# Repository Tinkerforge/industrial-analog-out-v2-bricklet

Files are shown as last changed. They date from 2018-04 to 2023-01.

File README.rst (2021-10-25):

Industrial Analog Out Bricklet 2.0
==================================

This repository contains the firmware source code and the hardware design
files. The documentation generator configs can be found at
https://github.com/Tinkerforge/generators

Repository Content
------------------

software/:
 * examples/: Examples for all supported languages
 * build/: Compiled files
 * src/: Source code of firmware
 * Makefile: Makefile to build project

hardware/:
 * Contains KiCad project files and additionally schematics as PDF

datasheets/:
 * Contains datasheets for sensors and complex ICs that are used

Hardware
--------

The hardware is designed with the open source EDA Suite KiCad
(http://www.kicad.org). Before you are able to open the files,
you have to install the Tinkerforge kicad-libraries
(https://github.com/Tinkerforge/kicad-libraries). You can either clone
them directly in hardware/ or clone them in a separate folder and
symlink them into hardware/
(ln -s kicad_path/kicad-libraries project_path/hardware). After that you
can open the .pro file in hardware/ with KiCad and from there view and
modify the schematics and the PCB layout.

Software
--------

If you want to do your own Brick/Bricklet firmware development we highly
recommend that you use our build environment setup script and read the
tutorial (https://www.tinkerforge.com/en/doc/Tutorials/Tutorial_Build_Environment/Tutorial.html).

To compile the C code we recommend you to install the newest GNU Arm Embedded
Toolchain (https://launchpad.net/gcc-arm-embedded/+download).
You also need to install bricklib2 (https://github.com/Tinkerforge/bricklib2).

You can either clone it directly in software/src/ or clone it in a
separate folder and symlink it into software/src/
(ln -s bricklib_path/bricklib2 project_path/software/src/). Finally make sure to
have CMake installed (http://www.cmake.org/cmake/resources/software.html).

After that you can build the firmware by invoking make in software/.
The firmware (.zbin) can then be found in software/build/ and uploaded
with brickv (click button "Flashing" on start screen).

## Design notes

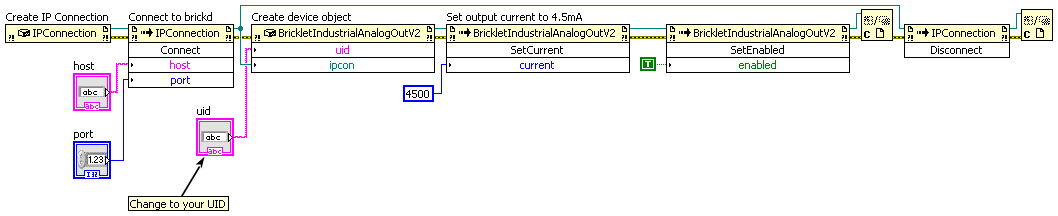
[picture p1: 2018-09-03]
software/examples/labview/Example Simple Current.vi.png

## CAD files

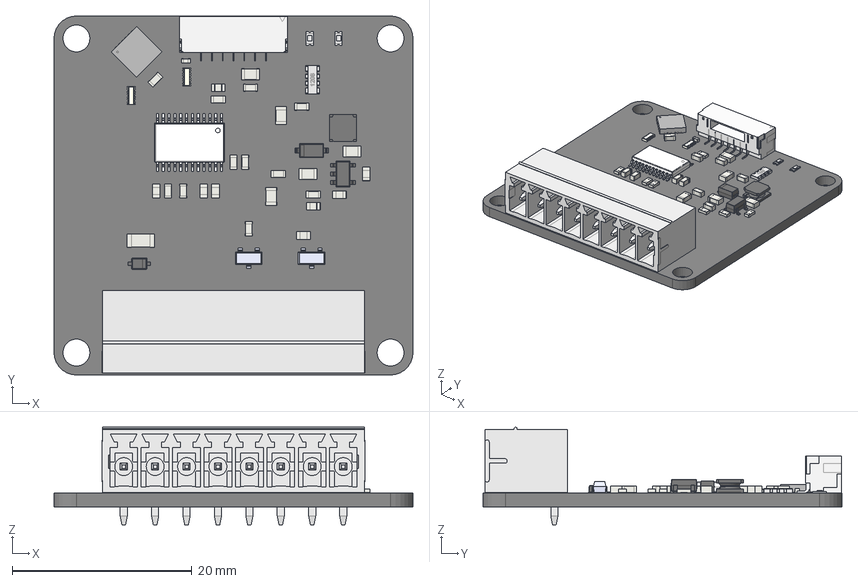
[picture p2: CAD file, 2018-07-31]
hardware/industrial-analog-out-v2.FCStd
40.0 x 40.0 x 10.9 mm
Pcb
R_0603_
R_0603_001
R_0603_002
R_0603_003
R_0603_004
R_0603_005
R_0603_006
R_0603_007
C_0603_
C_0603_001
C_0603_002
C_0603_003
C_0603_004
C_0603_005
C_0603_006
C_0603_007
C_0603_008
QFN-24_4x4mm_Pitch0.5mm_
BrickletConn_7pin_
D_0603_blue_
C_0603_009
C_0603_010
C_0805_
NR303_
TSSOP-24_
C_1206_
SOT23_
SOT23_001
SOD-123_
SOD323F_
8er_Phoenix_Buchse_
SOT-23-5_
C_0805_001
C_0805_002
C_0805_003
C_0805_004
D_0603_blue_001
R_4x0603_
C_0402_

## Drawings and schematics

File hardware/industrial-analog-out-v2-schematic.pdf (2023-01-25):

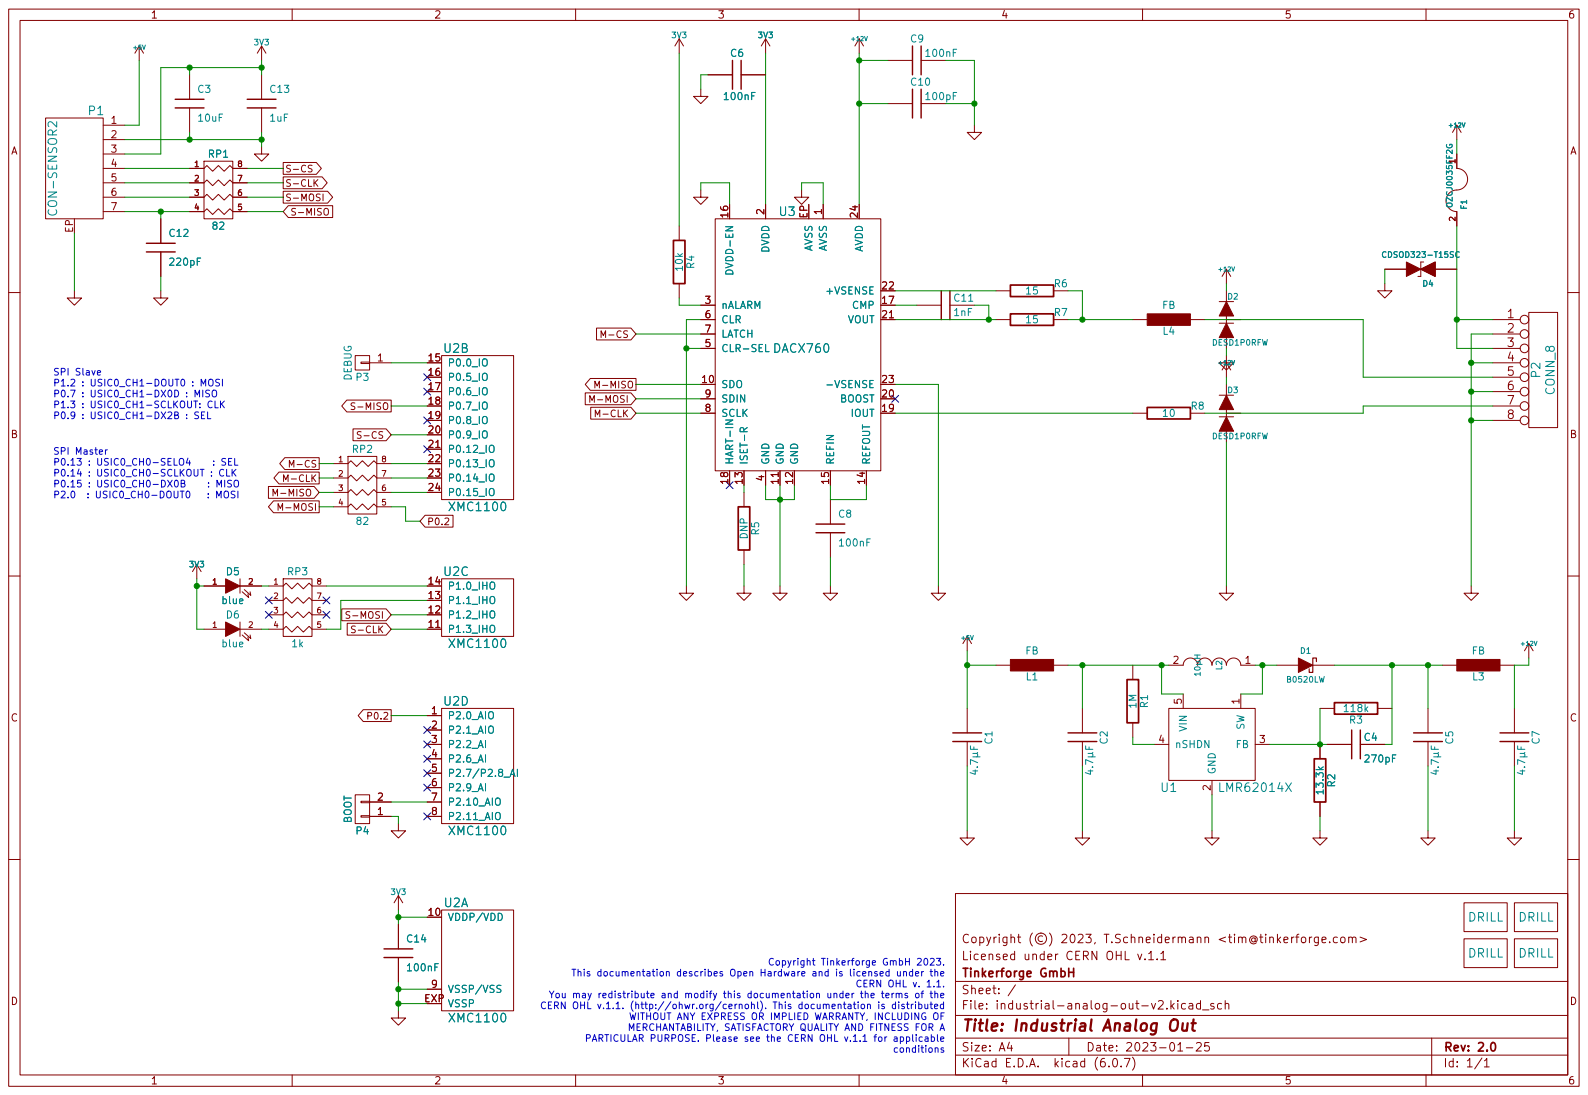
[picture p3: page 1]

5 2 2 | 7 7
6 3 3 | 6 6

1 SDO 10 GND 11 GND 12 ISET-R 13 REFOUT 14 REFIN 15 DVDD-EN 16 CMP 17 HART-IN 18

SPI Slave P1.2 : USIC0_CH1-DOUT0 : MOSI P0.7 : USIC0_CH1-DX0D : MISO

S-CS M-MOSI M-CS M-MISO

SPI Master P0.13 : USIC0_CH0-SELO4 : SEL P0.14 : USIC0_CH0-SCLKOUT : CLK

Licensed under CERN OHL v.1.1
File: industrial-analog-out-v2.kicad_sch Sheet: / Tinkerforge GmbH

Id: 1/1 Title: Industrial Analog Out

PARTICULAR PURPOSE. Please see the CERN OHL v.1.1 for applicable

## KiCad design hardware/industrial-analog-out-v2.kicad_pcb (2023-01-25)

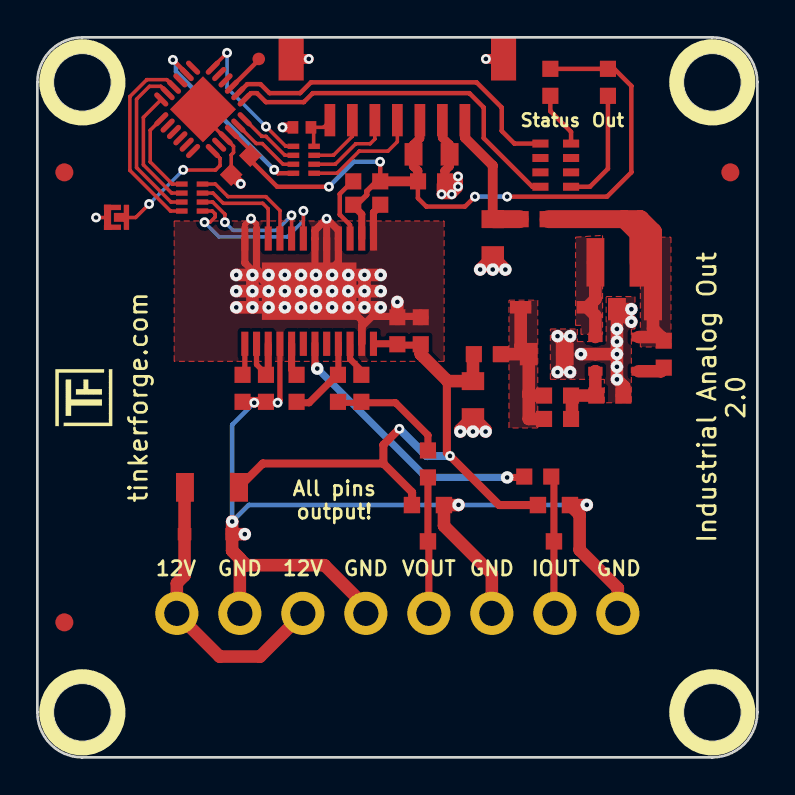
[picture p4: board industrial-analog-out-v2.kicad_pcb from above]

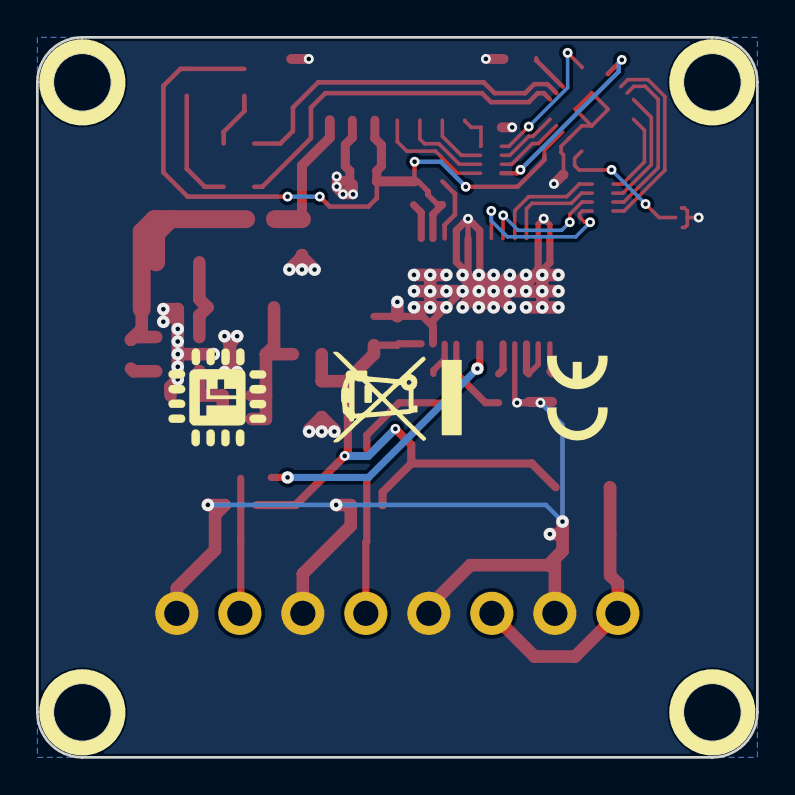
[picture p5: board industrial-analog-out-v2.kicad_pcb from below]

Board: 2 copper layers, 40.0 x 40.0 mm, 52 parts (2 on the bottom side), 42 nets.

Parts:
C1, C2, C5, C7: 4.7µF; C0805
C3: 10uF; C0805
C4: 270pF; C0603F
C6, C8, C9, C14: 100nF; C0603F
C10: 100pF; C0603F
C11: 1nF; C0603F
C12: 220pF; C0402F
C13: 1uF; C0603F
D1: B0520LW; SOD-123
D2, D3: DESD1P0RFW; SOT23-3
D4: CDSOD323-T15SC; SOD-323
D5, D6: blue; D0603F
F1: OZCJ0035FF2G; C1206
Fiducial_Mark: VAL**; Fiducial_Mark
Fiducial_Mark#2, Fiducial_Mark#3: VAL**; Fiducial_Mark
L1, L3, L4: FB; R0603F
L2: 10µH; NR3030
P1: CON-SENSOR2
P2: CONN_8; OQ_8P
P3: DEBUG; DEBUG_PAD
P4: BOOT; SolderJumper
R1: 1M; R0603F
R2: 13.3k; R0603F
R3: 118k; R0603F
R4: 10k; R0603F
R5: DNP; R0603F
R6, R7: 15; R0603F
R8: 10; R0603F
RP1, RP2: 82; 4X0402
RP3: 1k; 4X0603
U1: LMR62014X; SOT23-5
U2: XMC1100; QFN24-4x4mm-0.5mm
U3: DACX760; TSSOP24-44-PWR
U4, U5, U6, U7: DRILL; DRILL_NP
VAL: WEEE_7mm_back; WEEE_7mm
VAL#2: CE_5mm

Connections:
3V3: C3.1, C6.1, C13.1, C14.1, D5.1, D6.1, P1.3, R4.1, U2.10, U3.2
+5V: C1.2, L1.2, P1.1
+12V: C7.2, C9.2, C10.2, D2.2, D3.2, F1.1, L3.1, U3.24
GND: C1.1, C2.1, C3.2, C5.1, C6.2, C7.1, C8.2, C9.1, C10.1, C12.2, C13.2, C14.2, D2.1, D3.1, D4.2, P1.2, P1.EP, P2.2, P2.4, P2.6, P2.8, P4.1, R2.2, R5.2, U1.2, U2.9, U2.EXP, U3.1, U3.4, U3.5, U3.6, U3.11, U3.12, U3.16, U3.23
M-CLK: RP2.2, U3.8
M-CS: RP2.1, U3.7
M-MISO: RP2.3, U3.10
M-MOSI: RP2.4, U3.9
unnamed: C2.2, L1.1, L2.2, R1.1, U1.5
unnamed: C4.1, C5.2, D1.2, L3.2, R3.1
unnamed: C4.2, R2.1, R3.2, U1.3
unnamed: C8.1, U3.14, U3.15
unnamed: C11.1, R7.2, U3.21
unnamed: C11.2, U3.17
unnamed: C12.1, P1.7, RP1.4
unnamed: D1.1, L2.1, U1.1
unnamed: D2.3, L4.1, P2.5
unnamed: D3.3, P2.7, R8.1
unnamed: D4.1, F1.2, P2.1, P2.3
unnamed: D5.2, RP3.1
unnamed: D6.2, RP3.4
unnamed: L4.2, R6.1, R7.1
unnamed: P1.4, RP1.1
unnamed: P1.5, RP1.2
unnamed: P1.6, RP1.3
unnamed: P3.1, U2.15
unnamed: P4.2, U2.7
unnamed: R1.2, U1.4
unnamed: R4.2, U3.3
unnamed: R5.1, U3.13
unnamed: R6.2, U3.22
unnamed: R8.2, U3.19
unnamed: RP2.6, U2.24
unnamed: RP2.7, U2.23
unnamed: RP2.8, U2.22
unnamed: RP3.5, U2.13
unnamed: RP3.8, U2.14
P0.2: RP2.5, U2.1
S-CLK: RP1.7, U2.11
S-CS: RP1.8, U2.20
S-MISO: RP1.5, U2.18
S-MOSI: RP1.6, U2.12

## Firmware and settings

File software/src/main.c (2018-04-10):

/* industrial-analog-out-v2-bricklet
 * Copyright (C) 2018 Olaf Lüke <olaf@tinkerforge.com>
 *
 * main.c: Initialization for Industrial Analog Out V2 Bricklet
 *
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
 * You should have received a copy of the GNU Lesser General Public
 * License along with this library; if not, write to the
 * Free Software Foundation, Inc., 59 Temple Place - Suite 330,
 * Boston, MA 02111-1307, USA.
 */

#include <stdio.h>
#include <stdbool.h>

#include "configs/config.h"

#include "bricklib2/bootloader/bootloader.h"
#include "bricklib2/hal/system_timer/system_timer.h"
#include "bricklib2/logging/logging.h"
#include "communication.h"

int main(void) {
	logging_init();
	logd("Start Industrial Analog Out V2 Bricklet\n\r");

	communication_init();

	while(true) {
		bootloader_tick();
		communication_tick();
	}
}

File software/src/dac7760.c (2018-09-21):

/* industrial-analog-out-v2-bricklet
 * Copyright (C) 2018 Olaf Lüke <olaf@tinkerforge.com>
 * Copyright (C) 2018 Ishraq Ibne Ashraf <ishraq@tinkerforge.com>
 *
 * dac7760.c: Driver for DAC7760 DA converter 
 *
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
 * You should have received a copy of the GNU Lesser General Public
 * License along with this library; if not, write to the
 * Free Software Foundation, Inc., 59 Temple Place - Suite 330,
 * Boston, MA 02111-1307, USA.
 */

#include "dac7760.h"

#include "communication.h"
#include "configs/config_dac7760.h"

#include "bricklib2/utility/crc8.h"
#include "bricklib2/logging/logging.h"
#include "bricklib2/hal/spi_fifo/spi_fifo.h"
#include "bricklib2/hal/ccu4_pwm/ccu4_pwm.h"
#include "bricklib2/hal/system_timer/system_timer.h"

DAC7760 dac7760;

XMC_GPIO_CONFIG_t out_led_gpio_config = {
	.mode         = XMC_GPIO_MODE_OUTPUT_PUSH_PULL,
	.output_level = XMC_GPIO_OUTPUT_LEVEL_HIGH,
};

const XMC_GPIO_CONFIG_t out_led_pwm_config	= {
	.mode             = XMC_GPIO_MODE_OUTPUT_PUSH_PULL_ALT2,
	.input_hysteresis = XMC_GPIO_INPUT_HYSTERESIS_STANDARD,
	.output_level     = XMC_GPIO_OUTPUT_LEVEL_LOW,
};

void dac7760_init_spi(void) {
	dac7760.spi_fifo.baudrate = DAC7760_SPI_BAUDRATE;
	dac7760.spi_fifo.channel = DAC7760_USIC_SPI;

	dac7760.spi_fifo.rx_fifo_size = DAC7760_RX_FIFO_SIZE;
	dac7760.spi_fifo.rx_fifo_pointer = DAC7760_RX_FIFO_POINTER;
	dac7760.spi_fifo.tx_fifo_size = DAC7760_TX_FIFO_SIZE;
	dac7760.spi_fifo.tx_fifo_pointer = DAC7760_TX_FIFO_POINTER;

	dac7760.spi_fifo.clock_passive_level = DAC7760_CLOCK_PASSIVE_LEVEL;
	dac7760.spi_fifo.clock_output = DAC7760_CLOCK_OUTPUT;
	dac7760.spi_fifo.slave = DAC7760_SLAVE;

	dac7760.spi_fifo.sclk_port = DAC7760_SCLK_PORT;
	dac7760.spi_fifo.sclk_pin = DAC7760_SCLK_PIN;
	dac7760.spi_fifo.sclk_pin_mode = DAC7760_SCLK_PIN_MODE;

	dac7760.spi_fifo.select_port = DAC7760_SELECT_PORT;
	dac7760.spi_fifo.select_pin = DAC7760_SELECT_PIN;
	dac7760.spi_fifo.select_pin_mode = DAC7760_SELECT_PIN_MODE;

	dac7760.spi_fifo.mosi_port = DAC7760_MOSI_PORT;
	dac7760.spi_fifo.mosi_pin = DAC7760_MOSI_PIN;
	dac7760.spi_fifo.mosi_pin_mode = DAC7760_MOSI_PIN_MODE;

	dac7760.spi_fifo.miso_port = DAC7760_MISO_PORT;
	dac7760.spi_fifo.miso_pin = DAC7760_MISO_PIN;
	dac7760.spi_fifo.miso_input = DAC7760_MISO_INPUT;
	dac7760.spi_fifo.miso_source = DAC7760_MISO_SOURCE;

	spi_fifo_init(&dac7760.spi_fifo);
}

void dac7760_init(void) {
	memset(&dac7760, 0, sizeof(DAC7760));

	dac7760_init_spi();

	dac7760.value = 0;
	dac7760.voltage = 0;
	dac7760.current = 0;
	dac7760.enabled = false;
	dac7760.voltage_range = INDUSTRIAL_ANALOG_OUT_V2_VOLTAGE_RANGE_0_TO_10V;
	dac7760.current_range = INDUSTRIAL_ANALOG_OUT_V2_CURRENT_RANGE_4_TO_20MA;

	dac7760.value_update = true;
	dac7760.config_update = true;
	dac7760.control_update = true;

	dac7760.crc_enable = true;
	dac7760.write_length = 0;

	// Init out status LED
	dac7760.out_status_led_cfg.min = 0;
	dac7760.out_status_led_cfg.max = 10000;
	dac7760.out_status_led_cfg.out_status_led_show = DAC7760_OUT_STATUS_LED_SHOW_V;
	dac7760.out_status_led_cfg.out_led_flicker_state.config = LED_FLICKER_CONFIG_OFF;
	dac7760.out_status_led_cfg.config = INDUSTRIAL_ANALOG_OUT_V2_OUT_LED_CONFIG_SHOW_OUT_STATUS;
	dac7760.out_status_led_cfg.config_old = INDUSTRIAL_ANALOG_OUT_V2_OUT_LED_CONFIG_SHOW_OUT_STATUS;
	dac7760.out_status_led_cfg.config_out_status = INDUSTRIAL_ANALOG_OUT_V2_OUT_LED_STATUS_CONFIG_INTENSITY;

	XMC_GPIO_Init((XMC_GPIO_PORT_t *)PORT1_BASE, 1, &out_led_pwm_config);

	// PWM frequency = Core clock / 100
	ccu4_pwm_init((XMC_GPIO_PORT_t *)PORT1_BASE, 1, 1, 100);

	// Set to zero intensity
	ccu4_pwm_set_duty_cycle(1, 0);
}

void dac7760_write_register(const uint8_t reg, const uint16_t data) {
	uint8_t write_data[4] = {reg, data >> 8, data & 0xFF};
	write_data[3] = crc8(write_data, 3);
	spi_fifo_transceive(&dac7760.spi_fifo, 4, write_data);
	dac7760.write_length = 4;
}

void dac7760_tick(void) {
	uint16_t value = 0;
	SPIFifoState state = spi_fifo_next_state(&dac7760.spi_fifo);

	if(state & SPI_FIFO_STATE_ERROR) {
		loge("DAC7760 SPI error: %d (%d)\n\r", state, dac7760.spi_fifo.spi_status);
		dac7760_init_spi();
	} else if((state == SPI_FIFO_STATE_IDLE) | (state & SPI_FIFO_STATE_READY)) {
		if(dac7760.write_length == 0) {
			if(dac7760.crc_enable) {
				// Enable CRC and DUAL OUT (without sending CRC as fourth byte)
				uint8_t data[3] = {DAC7760_REG_WRITE_CONFIG, 1 << 0, 1 << 3};
				spi_fifo_transceive(&dac7760.spi_fifo, 3, data);
				dac7760.write_length = 3;
				dac7760.crc_enable = false;
				return;
			}

			if(dac7760.config_update) {
				// Enable DUAL OUTEN, CRC and set IOUT RANGE
				const uint16_t value = (1 << 3) | (1 << 8) | ((dac7760.current_range+1) << 9);
				dac7760_write_register(DAC7760_REG_WRITE_CONFIG, value);
				dac7760.config_update = false;
				return;
			}

			if(dac7760.control_update) {
				// Enable/Disable output and set VOUT RANGE
				const uint16_t value_control = (dac7760.enabled ? (1 << 12) : 0) | dac7760.voltage_range;
				dac7760_write_register(DAC7760_REG_WRITE_CONTROL, value_control);
				dac7760.control_update = false;
				return;
			}

			if(dac7760.value_update) {
				dac7760_write_register(DAC7760_REG_WRITE_DAC, dac7760.value << 4);
				dac7760.value_update = false;
				return;
			}
		} else {
			uint8_t data[16];
			uint16_t length = spi_fifo_read_fifo(&dac7760.spi_fifo, data, 16);
			if(length != dac7760.write_length) {
				loge("DAC7760 unexpected write length: %d (length) != %d (expected length)\n\r", length, dac7760.write_length);
				dac7760_init_spi();
				dac7760.value_update = true;
			}

			dac7760.write_length = 0;
		}
	}

	// Manage out LED
	if (dac7760.out_status_led_cfg.config != dac7760.out_status_led_cfg.config_old) {
		if (dac7760.out_status_led_cfg.config == INDUSTRIAL_ANALOG_OUT_V2_OUT_LED_CONFIG_SHOW_OUT_STATUS) {
			XMC_GPIO_Init((XMC_GPIO_PORT_t *)PORT1_BASE, 1, &out_led_pwm_config);

			// PWM frequency = Core clock / 100
			ccu4_pwm_init((XMC_GPIO_PORT_t *)PORT1_BASE, 1, 1, 100);

			// Set to zero intensity
			ccu4_pwm_set_duty_cycle(1, 0);
		}
		else {
			XMC_GPIO_Init((XMC_GPIO_PORT_t *)PORT1_BASE, 1, &out_led_gpio_config);

			// Turn off the LED
			XMC_GPIO_SetOutputHigh((XMC_GPIO_PORT_t *)PORT1_BASE, 1);
		}

		dac7760.out_status_led_cfg.config_old = dac7760.out_status_led_cfg.config;
	}

	switch (dac7760.out_status_led_cfg.config) {
		case INDUSTRIAL_ANALOG_OUT_V2_OUT_LED_CONFIG_OFF:
			dac7760.out_status_led_cfg.out_led_flicker_state.config = LED_FLICKER_CONFIG_OFF;
			XMC_GPIO_SetOutputHigh((XMC_GPIO_PORT_t *)PORT1_BASE, 1);

			break;

		case INDUSTRIAL_ANALOG_OUT_V2_OUT_LED_CONFIG_ON:
			dac7760.out_status_led_cfg.out_led_flicker_state.config = LED_FLICKER_CONFIG_ON;
			XMC_GPIO_SetOutputLow((XMC_GPIO_PORT_t *)PORT1_BASE, 1);

			break;

		case INDUSTRIAL_ANALOG_OUT_V2_OUT_LED_CONFIG_SHOW_HEARTBEAT:
			dac7760.out_status_led_cfg.out_led_flicker_state.config = LED_FLICKER_CONFIG_HEARTBEAT;
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

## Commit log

2018-03-13 Add schematic
    [industrial-analog-out.sch]
2018-03-13 Assign missing footprints
    [industrial-analog-out.sch]
2018-03-13 Connect dac7760 to mcu
    [industrial-analog-out.sch]
2018-03-13 Fix some pins
    [industrial-analog-out.sch]
2018-03-13 Add layout
    [industrial-analog-out.kicad_pcb]
2018-03-13 Add all logos
    [industrial-analog-out.kicad_pcb]
2018-03-19 added second led, not fully routed
    [industrial-analog-out.kicad_pcb, industrial-analog-out.sch]
2018-03-19 routing finished, logo placement fixed
    [industrial-analog-out.kicad_pcb]
2018-03-19 fix status text
    [industrial-analog-out.kicad_pcb]
2018-04-10 Add auto-generated stub firmware
    [cmake_config_custom.txt]
2018-04-10 Use correct pin defines for SPI, LEDs and debug
    [config_custom_bootloader.h, config_custom_bootstrapper.h]
2018-04-11 Add DAC7760 driver
2018-04-17 Use USIC SPI instead of CHANNEL (removes warning)
2018-05-11 Rename files
    [industrial-analog-out-v2.kicad_pcb, industrial-analog-out-v2.sch]
2018-06-06 fix fiducials
    [industrial-analog-out-v2.kicad_pcb, industrial-analog-out-v2.sch]
2018-06-18 Change capacitor footprint(s) to C0402F
    [industrial-analog-out-v2.kicad_pcb, industrial-analog-out-v2.sch]
2018-07-17 specify processor
    [industrial-analog-out-v2.kicad_pcb, industrial-analog-out-v2.sch]
2018-07-27 Channel status LED implementation
2018-07-31 Add 3d models (*.FCStd & *.step)
    [industrial-analog-out-v2.FCStd]
2018-07-31 Add PDF schematic
2018-08-17 remap for kicad 5.0, add sym table
    [industrial-analog-out-v2.sch]
2018-09-21 Rename Channel LED to Out LED and remove unused channel parameter
2020-09-02 uc: Add example driver note.
2021-02-09 fix inductor footprints
    [industrial-analog-out-v2.kicad_pcb, industrial-analog-out-v2.sch]
2021-10-25 Update KiCad link
    https://www.kicad.org/blog/2021/10/Avoid-links-to-former-kicad-domain/
2023-01-23 New standart layout. Switched to Kicad 6
    [industrial-analog-out-v2.kicad_pcb, industrial-analog-out-v2.kicad_sch, industrial-analog-out-v2.sch]
2023-01-25 remove rescue lib stuff
    [industrial-analog-out-v2.kicad_sch]
2023-01-25 Data Cleanup
    [industrial-analog-out-v2.kicad_pcb, industrial-analog-out-v2.kicad_sch]

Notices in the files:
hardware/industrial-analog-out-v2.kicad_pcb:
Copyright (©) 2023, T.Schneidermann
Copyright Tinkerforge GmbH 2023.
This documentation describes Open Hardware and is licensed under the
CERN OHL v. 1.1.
